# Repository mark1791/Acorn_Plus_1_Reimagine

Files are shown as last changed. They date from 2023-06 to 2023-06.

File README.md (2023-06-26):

# Acorn Plus 1 Reimagine
Recreation of the Acorn Plus 1 based off of original schematic and redrawn schematic

Goal was to recreate as much as possible the schematic and design of the original PCB and to use descrit components.

Issues sourcing components as some are no longer made. Cost to make is >£100, PCB's £11 each PCBway used to make boards

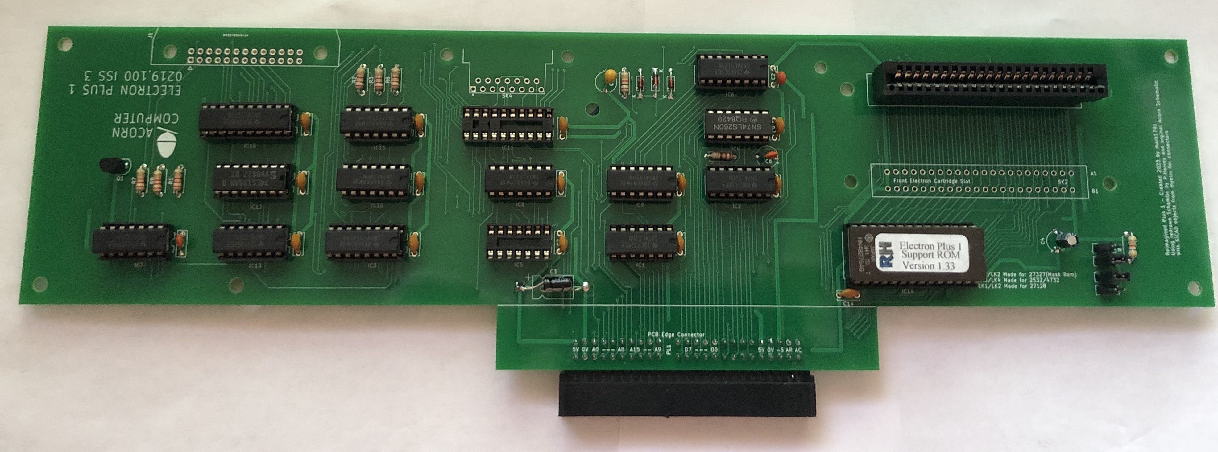
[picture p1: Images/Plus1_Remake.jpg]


## V1.1.1 Updated version
Missed a hole off on lower left for mounting PCB to Case. 
Note :- Version 1.1/1.1.1 not made into PCB's yet as of 26/06/23

## V1.1 Second version
Issues fixed listed below found in V1 and other issues on Stardot

## V1 First version created June 2023.
Using original schematic from Acorn and redrawn schematic by P.Harvey

Points to note, redrawn schematic has -5V going to Analogue port should be +5V

Pin 2 of IC6 needs connecting to Pin 3 of IC8.

Also used the excellent work of myelin and his KiCad files for the connectors

https://github.com/myelin/myelin-kicad.pretty

## Other issues to correct:-(Fixed on V1.1)

IC6 needs moving 1.2mm up so AP6 board will fit.

Two holes missing one mounting hole and one hole by lower edge connector.

Resistor size chosen a bit small just fits.

Left analogue hole needs to be moved 2mm as doesnt align with lower case.

IC8 Ground connection on back needs increasing 1mm.

Recheck layout and tidy up visual issues.

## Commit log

2023-06-22 First upload of KiCad files
    [001-Acorn-Electron-Plus1.kicad_sch]
2023-06-26 V1.1 upload with all changes from Stardot and other issues found
    Change 74LS260 Symbol to to a NOR Gate not a NAND gate
    Change all Decoupling Caps to 100nF
    Change PHI2 to PHI0
    Move Left Analogue hole to line up with Molding mounting hole post
    Move IC6 up 1.6mm to allow for AP6 to fit.
    1 Holes missing around Cartrigde Slot
    Connect IC6 pin 2 to Pin 3 IC8 - ROMQA
    Tidy up some routing on the PCB
    Delete ground connection on IC5 that shouldnt be there.
    [001-Acorn-Electron-Plus1.kicad_sch]
2023-06-26 V1.1.1 Missed a hole off
    One mounting hole missed
